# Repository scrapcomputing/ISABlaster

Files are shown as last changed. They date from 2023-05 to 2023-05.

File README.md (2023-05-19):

# ISA Blaster
A PCB for a software-defined ISA card powered by a Raspberry Pi Pico micro-controller.
All the logic for interfacing to the ISA bus is done in software.

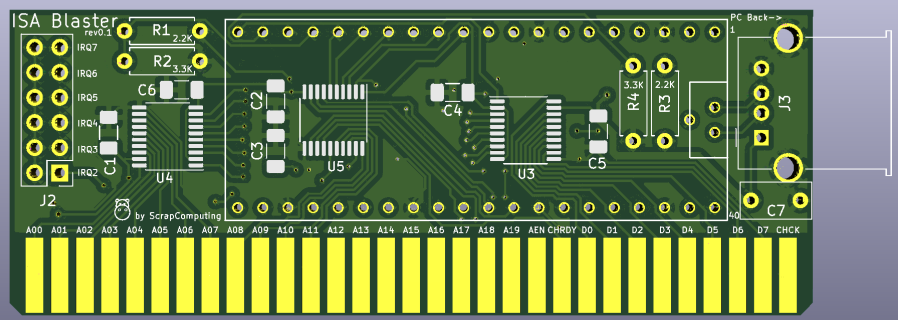
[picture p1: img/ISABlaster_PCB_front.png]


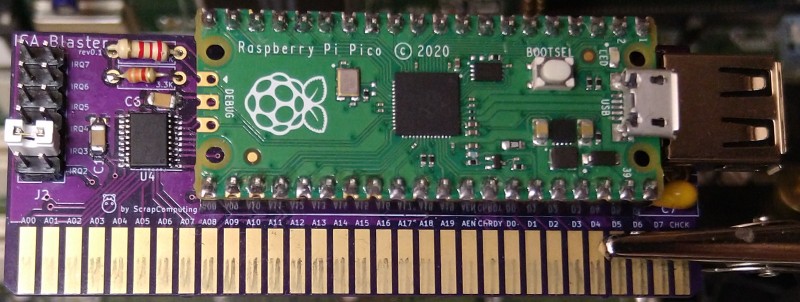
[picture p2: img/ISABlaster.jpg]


# Projects based on the ISA Blaster

## DirtyRat USB Mouse Adapter
We can use the ISA Blaster as a USB mouse adapter card.
This allows you to use a USB mouse on your vintage DOS PC without the need for an external adapter.
This requires the use of:

1. The DirtyRat mouse driver for DOS: <https://github.com/scrapcomputing/DirtyRatDriver>, and
2. The DirtyRat Firmware for the Pico: <https://github.com/scrapcomputing/DirtyRatFirmware>.

# How to load the firmware
- Unplug the ISA Blaster from the motherboard
- Remove any connected USB devices (e.g., mouse)
- Press and hold the small button on the Pico
- While holding the button, connect the Pico to your PC with a micro-USB cable
- The Pico should show up as a mass-storage device
- Copy the firmware to the drive associated with the Pico
- Safely eject the mass-storage device

# Bill of materials

Gerber files are published in the releases: https://github.com/scrapcomputing/ISABlaster/releases

Item                               | # | Description
-----------------------------------|---|--------------------------------------------------------
Raspberry Pi Pico                  | 1 |
1x20-pin 2.54mm Female Headers     | 2 | For plugging in the Pico
1x20-pin 2.54mm Male Headers       | 2 | For the Pico
TXS0108EPW 20TSSOP                 | 3 | Bidirectional level-shifters 3.3V/5V
2x6 2.54mm Male Pin Headers        | 1 | For the IRQ selection
2.54mm Jumper                      | 1 | For the IRQ selection
0.1uF 1206 SMD capacitors          | 6 | Decoupling capacitors for the ICs C1-6
2.2K through-hole resistor 1/8W    | 2 | * Better to leave them unpopulated: See "Known Issues" below
3.3K through-hole resistor 1/8W    | 2 | * Better to leave them unpopulated: See "Known Issues" below
1uF through-hole ceramic capacitor | 1 | Smoothing capacitor for the board.
Horizontal Female USB connector    | 1 | For plugging in a USB device.
3-4cm short jumper wires           | 2 | For connecting Pico's TP2,TP3 pads to the PCB's pads for the on-bard USB connector

# Known Issues
- Rev0.1 connects MEMR and MEMW to voltage dividers which are made up by the 2.2K and 3.3K through-hole resistors.
  The voltage dividers can cause issues on some motherboards, so it is better to leave them unpopulated.
  This will be fixed in a later revision of the board.

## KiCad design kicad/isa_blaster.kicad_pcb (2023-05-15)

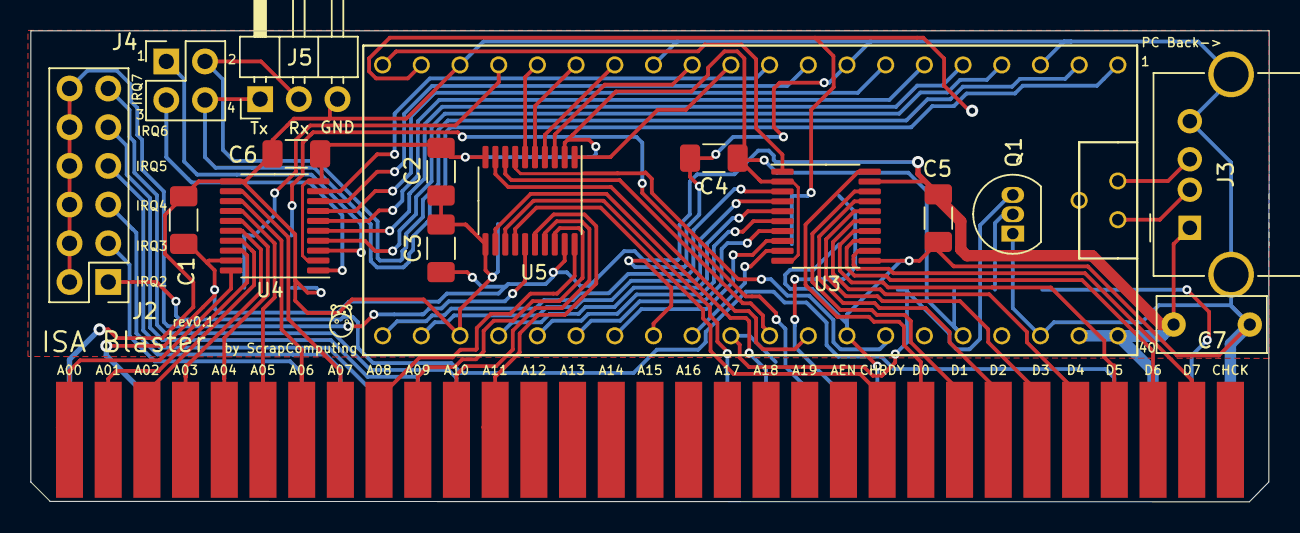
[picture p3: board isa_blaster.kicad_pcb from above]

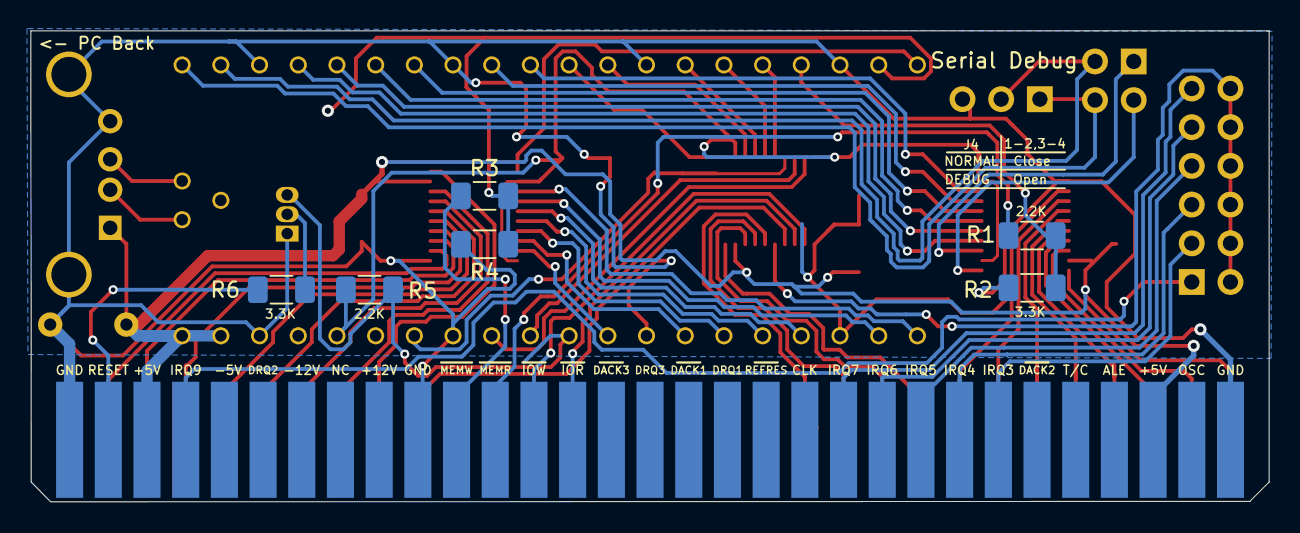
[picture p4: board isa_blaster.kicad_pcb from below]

Board: 2 copper layers, 81.3 x 30.9 mm, 23 parts (6 on the bottom side), 68 nets.

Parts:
C1, C2, C3, C4, C5, C6: 0.1u; C_1206_3216Metric_Pad1.33x1.80mm_HandSolder
C7: 10uF; C_Rect_L7.0mm_W3.5mm_P5.00mm
J1: Bus_ISA_8bit; 8bit_BUS_AT
J2: Conn_02x06_Odd_Even; PinHeader_2x06_P2.54mm_Vertical
J3: USB_A; USB_A_Molex_67643_Horizontal
J4: Conn_02x02_Odd_Even; PinHeader_2x02_P2.54mm_Vertical
J5: Conn_01x03; PinHeader_1x03_P2.54mm_Horizontal
Q1: 2N3904; TO-92_Inline
R1, R3, R5: 2.2K; R_1206_3216Metric_Pad1.30x1.75mm_HandSolder
R2, R4, R6: 3.3K; R_1206_3216Metric_Pad1.30x1.75mm_HandSolder
U3, U4, U5: TXS0108EPW; TSSOP-20_4.4x6.5mm_P0.65mm
U6: RaspberryPi_Pico; raspberry_pi_pico

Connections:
+3V3: C2.1, C4.1, C6.1, R5.1, U3.2, U3.10, U4.2, U4.10, U5.2, U5.10, U6.36
+5V: C1.1, C3.1, C5.1, C7.2, J1.3, J1.29, J3.1, U3.19, U4.19, U5.19, U6.39, U6.40
GND: C1.2, C2.2, C3.2, C4.2, C5.2, C6.2, C7.1, J1.1, J1.10, J1.31, J3.4, J3.5, J5.3, Q1.1, R2.2, R4.2, U3.11, U4.11, U5.11, U6.3, U6.8, U6.13, U6.18, U6.23, U6.28, U6.33, U6.38
unnamed: J1.2, R6.1
unnamed: J1.4, J2.1
unnamed: J1.11, R3.1
unnamed: J1.12, R1.1
unnamed: J1.13, U5.12
unnamed: J1.14, U5.13
unnamed: J1.21, J2.11
unnamed: J1.22, J2.9
unnamed: J1.23, J2.7
unnamed: J1.24, J2.5
unnamed: J1.25, J2.3
unnamed: J1.33, U3.12
unnamed: J1.34, U3.13
unnamed: J1.35, U3.14
unnamed: J1.36, U3.15
unnamed: J1.37, U3.16
unnamed: J1.38, U3.17
unnamed: J1.39, U3.18
unnamed: J1.40, U3.20
unnamed: J1.41, U5.14
unnamed: J1.51, U5.16
unnamed: J1.52, U5.17
unnamed: J1.53, U5.18
unnamed: J1.54, U5.20
unnamed: J1.55, U4.12
unnamed: J1.56, U4.13
unnamed: J1.57, U4.14
unnamed: J1.58, U4.15
unnamed: J1.59, U4.16
unnamed: J1.60, U4.17
unnamed: J1.61, U4.18
unnamed: J1.62, U4.20
unnamed: J2.2, J2.4, J2.6, J2.8, J2.10, J2.12, U5.15
unnamed: J3.2, U6.42
unnamed: J3.3, U6.43
unnamed: J4.1, U4.3
unnamed: J4.2, J5.2, U6.2
unnamed: J4.3, U4.1
unnamed: J4.4, J5.1, U6.1
unnamed: Q1.2, R6.2
unnamed: Q1.3, R5.2, U6.30
unnamed: R1.2, R2.1, U6.17
unnamed: R3.2, R4.1, U6.19
unnamed: U3.1, U6.20
unnamed: U3.3, U6.21
unnamed: U3.4, U6.22
unnamed: U3.5, U6.24
unnamed: U3.6, U6.25
unnamed: U3.7, U6.26
unnamed: U3.8, U6.27
unnamed: U3.9, U6.29
unnamed: U4.4, U6.4
unnamed: U4.5, U6.5
unnamed: U4.6, U6.6
unnamed: U4.7, U6.7
unnamed: U4.8, U6.9
unnamed: U4.9, U6.10
unnamed: U5.1, U6.11
unnamed: U5.3, U6.12
unnamed: U5.4, U6.14
unnamed: U5.5, U6.15
unnamed: U5.6, U6.16
unnamed: U5.7, U6.34
unnamed: U5.8, U6.31
unnamed: U5.9, U6.32

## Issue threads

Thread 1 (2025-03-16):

BOM and new smd layout seems not to fit

sfambach, 2025-03-16:
Hi, first of all thanks for this Project, this is already the second PCP I made from your projects. I have a little trouble to get the PCB running it is not showing as COM port. So I try to check the components. The bom on github seems to be a little bit outdated or at least does not fit to the gerber files.

The value of the Transistor I got from the schematic. But I am wondering if the R1-R6 Resitors should still not be populated of if this is fixed?

It would be nice if you could find the time to give me a short hint.

BR
Stefan

scrapcomputing, 2025-03-16:
Hi Stefan,

Sorry for the poor documentation, I had been working on a redesigned board for a while, but haven't got into testing it and releasing it.

As for the rev.0.1 boards, there is no need to populate the R1-R4 resistors, because some motherboards may not boot with them installed.

The [DirtyRat firmware](https://github.com/scrapcomputing/DirtyRatFirmware) does not emulate a COM port. It works more like a bus-mouse interface in combination with the [DirtyRat DOS Driver](https://github.com/scrapcomputing/DirtyRatDriver). When you load the DirtyRat driver make sure you have a USB mouse plugged in, and you should see a message that a mouse is found, similar to the one you see when loading the ctmouse driver.

As for troubleshooting I would check:
- That the Pico's TP2 and TP3 USB pads (at the back side of the Pico) are connected to the board's USB pins (which sadly are not marked on the rev.0.1 boards but correspond one-to-one to the Pico's pads).
- That there are no solder bridges across the level-shifter pins.
- The IRQ jumper is set and matches the one that the DirtyRat driver uses.

Please note that some motherboard chipsets are quite picky with and may not work even with the [DirtyRatFirmware rev0.1_pio](https://github.com/scrapcomputing/DirtyRatFirmware/releases/download/rev0.1/DirtyRatFirmware_rev.0.1_pio.uf2).

Please let me know if you are still having issues, I would be happy to help with troubleshooting.

sfambach, 2025-03-18:
Hi again and thanks for the fast answer and the hints.

I am a big moron, I thougt it must be a com emulation and did not test the driver because I saw no port registration during bootup.  So I installed the Driver and at least for the second board is working.  For the first card Ill check the level shifter, maybe I broke one during soldering the contacts are looking fine.

Many thanks let me know if I can spend a coffe anywhere.
Stefan

Closed 2025-03-18.

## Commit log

2023-05-15 Rev 0.1
    [isa_blaster.kicad_pcb, isa_blaster.sch]
2023-05-15 Added RESET circuit, debug header and SMD resistors
    [isa_blaster.kicad_pcb, isa_blaster.sch]
